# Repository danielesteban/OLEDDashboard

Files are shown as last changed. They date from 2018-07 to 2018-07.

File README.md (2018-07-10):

OLED Dashboard
==============

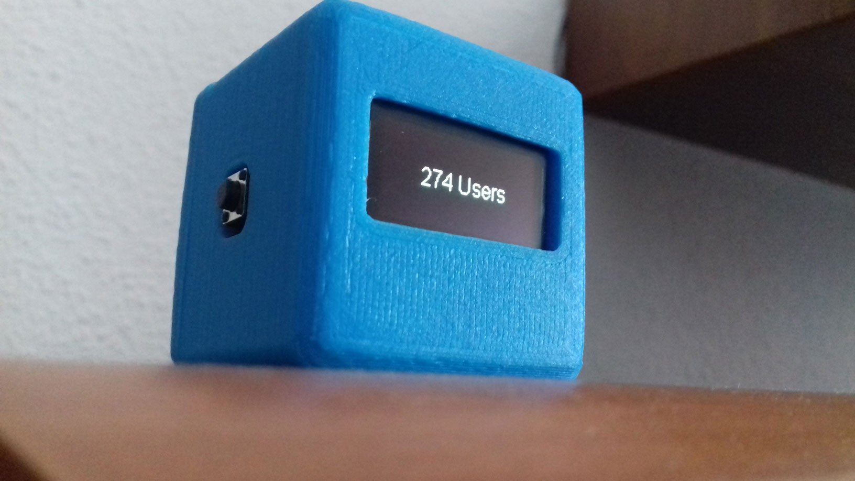
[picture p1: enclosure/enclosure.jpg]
Enclosure


#### Part list

- [3D printed enclosure](enclosure/enclosure.stl)
- SSD1306 OLED display
- 4 angled female headers
- 8 straight female headers
- 1 10µf decoupling capacitor
- 1 L1117 3.3v voltage regulator
- 1 ESP8266 module (ESP-01 package)
- 2 Push buttons
- 4 pieces of perfboard
- A bunch of wire & some solder

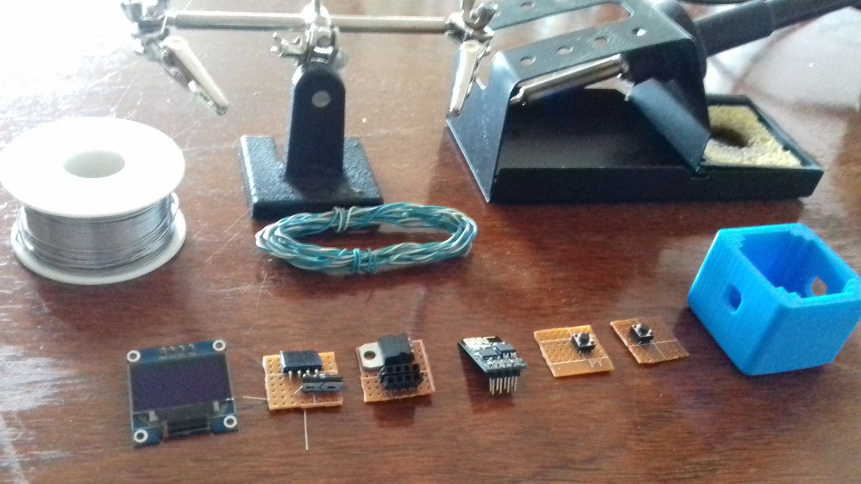
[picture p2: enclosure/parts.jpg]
Parts


#### Edit server config in: [src/config.h](src/config.h)

```c++
// Server config
struct {
  const char* server;
  const uint16_t port;
  const char* path;
  const char* thumbprint;
  const bool tls;
  const char* version;
} config = {
  "SERVER_HOST", 443, "/",
  "TLS_CERT_THUMBPRINT", true,
  FIRMWARE_VERSION
};
```

##### The first time, you'll need to upload the sketch over serial (using a Raspberry PI's UART or a USB2TTL dongle):
`platformio run --target=upload --upload-port=SERIAL_PORT`

#### Network config:

- Hold the secondary button while powering the board
- It will start a WiFi access point with the ssid: "OLED-YOUR_CHIP_ID".
- The OLED will display a random password
- Use that password to connect to that network with any device that has a web browser
- Visit: http://192.168.1.1/
- Select a network, type the password and hit submit
- The board will automatically restart and resume normal operation.

#### Pushing data:

```js
const server = new Server();
// This will be sent to all connected clients that have that stream selected
// The last frame is cached to be sent when clients switch to the stream
server.push(UINT8_STREAM_ID, 'Arbitrary data');
// You can also push images
const image = Image.fromFile(path.join(__dirname, 'test.png'));
server.push(UINT8_STREAM_ID, image);
```

You can see some example streams in: [server/index.js](server/index.js).

#### Dev Server:

- cd server
- yarn install
- yarn dev

While in development, the server will watch the output directory of platformio and every time you run "platformio run" it will try to push the firmware to all connected clients.

#### Production Server:

- cd server
- docker-compose -p DashboardServer up -d --build

While in production, the latest firmware inside the '[server/firmwares](server/firmwares)' folder will be flashed to all clients with a prior version. The firmware filenames should follow the naming convention: `MAJOR.MINOR.PATCH.bin`

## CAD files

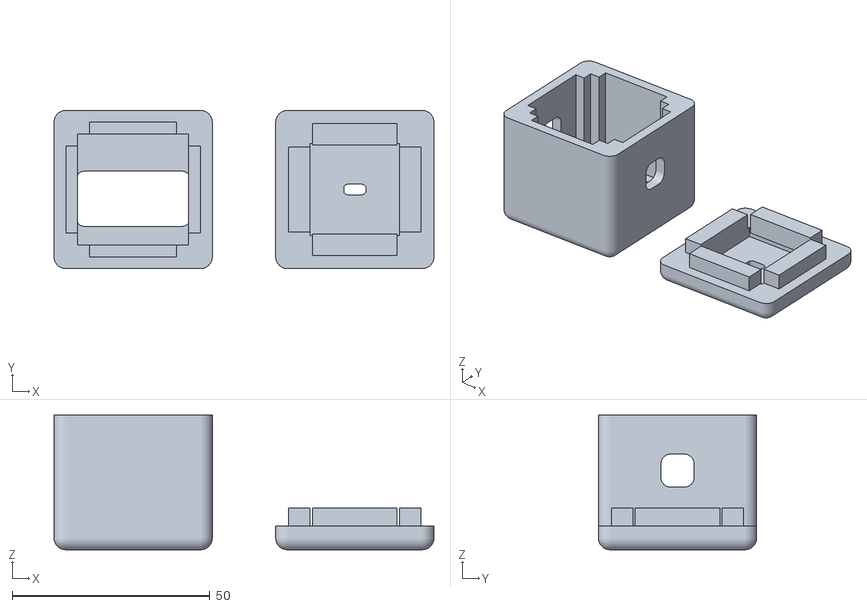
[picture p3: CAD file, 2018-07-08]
enclosure/enclosure.stl
96.0 x 40.0 x 34.0

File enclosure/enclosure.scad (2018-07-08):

// Parametric dimensions
WALL = 6;
WIDTH = 28;
LENGTH = 28;
HEIGHT = 28;

// Lid labels
// $LID_LABEL_TOP = "OLED";
// $LID_LABEL_BOTTOM = "DASHBOARD";
// $LID_LABEL_BOTTOM_SIZE = 4;

// Select what to export
EXPORT_ENCLOSURE = true;
EXPORT_LID = true;

// Rounded box helper
module Box(width, length, height, corner = 0.15) {
  scale([width, length, height]) {
    minkowski() {
      cube([1 - corner, 1 - corner, 1 - corner], center = true);
      sphere($fn=64, d=corner, center = true);
    }
  }
}

// Enclosure
if (EXPORT_ENCLOSURE)
translate([EXPORT_LID ? -WIDTH : 0, 0, 0])
rotate([0, 180, 180])
color("Blue") {
  difference() {
    // Main body
    Box(WIDTH + (WALL * 2), LENGTH + (WALL * 2), HEIGHT + (WALL * 2));
    // Make it hollow
    translate([0, 0, WALL * -0.25]) {
      cube([WIDTH, LENGTH, HEIGHT + WALL * 2], center = true);
    }
    // Cut open the bottom
    translate([0, 0, -(HEIGHT + (WALL * 2)) + WALL]) {
      cube([WIDTH * 2, LENGTH * 2, HEIGHT + (WALL * 2)], center = true);
    }
    // Display window
    translate([0, (LENGTH * 0.25) - (LENGTH * 0.5) / 3, HEIGHT * 0.5]) {
      Box(WIDTH , (LENGTH * 0.5), HEIGHT);
    }
    // Board beds
    offset = WALL * 0.5;
    for (a = [0:3]) {
      rotate([0, 0, 90 * a]) {
        translate([0, LENGTH * 0.5, offset * -0.5]) {
          cube([
            WIDTH - (offset * 2),
            offset * 2,
            HEIGHT + offset
          ], center = true);
        }
      }
    }
    // Buttons windows
    for (a = [1,3]) {
      rotate([0, 0, 90 * a]) {
        translate([0, LENGTH * 0.5, 0]) {
          Box(WIDTH * 0.3, LENGTH, WIDTH * 0.3, 0.6);
        }
      }
    }
  }
}

// Lid
if (EXPORT_LID)
translate([EXPORT_ENCLOSURE ? WIDTH : 0, 0, 0])
color("Blue") {
  union() {
    difference() {
      // Main body
      Box(WIDTH + (WALL * 2), LENGTH + (WALL * 2), HEIGHT + (WALL * 2));
      // Make it hollow
      translate([0, 0, WALL * 0.5]) {
        cube([WIDTH - WALL * 0.9, LENGTH - WALL * 0.8, HEIGHT + WALL * 2], center = true);
      }
      // Cut the top out
      translate([0, 0, WALL]) {
        cube([WIDTH * 2, LENGTH * 2, HEIGHT + (WALL * 2)], center = true);
      }
      // Power cord window
      translate([0, 0, HEIGHT * -0.5]) {
        Box(WIDTH * 0.2, WIDTH * 0.1, HEIGHT, 0.6);
      }
      // Labels
      translate([0, 0, HEIGHT * -0.5 - WALL * 0.75])
      rotate([180, 0, 180]) {
        if ($LID_LABEL_TOP != undef)
        translate([0, LENGTH * (1/3), 0])
        scale([1, 2, 1])
        linear_extrude(height = WALL) {
          size = $LID_LABEL_TOP_SIZE == undef ? 5 : $LID_LABEL_TOP_SIZE;
          text($LID_LABEL_TOP, size = size, font = "monospace", halign = "center", valign = "center", $fn = 16);
        }
        if ($LID_LABEL_BOTTOM != undef)
        translate([0, LENGTH * -(1/3), 0])
        scale([1, 2, 1])
        linear_extrude(height = WALL) {
          size = $LID_LABEL_BOTTOM_SIZE == undef ? 5 : $LID_LABEL_BOTTOM_SIZE;
          text($LID_LABEL_BOTTOM, size = size, font = "monospace", halign = "center", valign = "center", $fn = 16);
        }
      }
    }
    // Pressure fits
    offset = WALL * 0.5;
    for (a = [0:3]) {
      rotate([0, 0, 90 * a]) {
        translate([0, LENGTH * 0.5, HEIGHT * -0.5 + offset * 0.5]) {
          cube([
            WIDTH - (offset * 2.2),
            offset * 1.8,
            offset * 2
          ], center = true);
        }
      }
    }
  }
}

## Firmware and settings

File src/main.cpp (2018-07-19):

// OLED Dashboard
// ===============
// dani@gatunes © 2018

#include <OLEDApp.h>
#include <UpdatableClient.h>
#include "config.h"

// App
void onButton(uint8_t button);
OLEDApp app(PRIMARY_BUTTON, SECONDARY_BUTTON, DISPLAY_SDA, DISPLAY_SCL, onButton);

// Client
void onImage(uint8_t width, uint8_t height, const uint8_t* image);
void onMessage(const char* message);
void onUpdate(const uint8_t percent);
UpdatableClient client(onImage, onMessage, onUpdate);

// Auto-pagination
#ifdef AUTOPAGINATION
uint32_t autoPaginationTimer = 0;
#endif

void onButton(uint8_t button) {
  // Paginate between streams
  switch (button) {
    case 0:
      client.previousStream();
    break;
    case 1:
      client.nextStream();
      break;
  }
  #ifdef AUTOPAGINATION
  autoPaginationTimer = millis();
  #endif
}

void onImage(uint8_t width, uint8_t height, const uint8_t* image) {
  app.drawImage(width, height, image);
}

void onMessage(const char* message) {
  app.print(message);
}

void onUpdate(const uint8_t percent) {
  if (percent == 100) {
    app.display.displayOff();
  } else {
    app.progress(percent);
  }
}

void setup() {
  app.setup();
  #ifdef BRIGHTNESS
  app.setBrightness(BRIGHTNESS);
  #endif
  client.setup(
    config.server, config.port, config.path, config.thumbprint, config.tls,
    config.version
  );
}

void loop() {
  app.loop();
  client.loop();
  #ifdef AUTOPAGINATION
  const uint32_t now = millis();
  if ((now - autoPaginationTimer) >= AUTOPAGINATION) {
    autoPaginationTimer = now;
    client.nextStream();
  }
  #endif
}

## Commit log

2018-07-04 Couple fixes
2018-07-05 3D printed enclosure (First draft)
    [enclosure.scad, enclosure.stl]
2018-07-06 Adjust enclosure sizes after test prints.. also added labels on the lid
    [enclosure.scad, enclosure.stl]
2018-07-07 Final enclosure
    [enclosure.scad, enclosure.stl]
2018-07-07 Swap buttons
2018-07-07 Add enclosure to the part list
2018-07-08 Make lid labels optional and export a clean STL version
    [enclosure.scad, enclosure.stl]
